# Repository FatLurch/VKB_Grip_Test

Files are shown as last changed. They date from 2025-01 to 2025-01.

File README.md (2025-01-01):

# VKB_Grip_Test

Basic Arduino Joystick interface to VKB MCG Pro grip

## Disclaimer

This information is provided without warranty - USE AT YOUR OWN RISK. 
Also, if you're looking for elegant design or code, you are in the wrong place.

## Overview

This project is intended to wire an Arduino Pro Micro directly to a VKB MCG Pro grip so that the Arduino can output the status of the grip as a Joystick using standard Windows joystick drivers.

## Circuit

The VKB grip uses a weird half-duplex UART line to transmit and recieve. In layman's terms, The TX and RX are tied together.

For my specific build I had a few Arduino Pro Micros laying around. This complicated things a bit since it uses 5V UART (The VKB grip is using 3.3V). There's a chance the UART pin on the STM32 microcontroller in the grip is 5V tolerant, but I wasn't feeling gutsy enough to try it, even if I were to dig in and verify the pin per the spec sheet. Ref: [https://community.st.com/t5/stm32-mcus-products/stm-uart-communication-voltage/td-p/288531](https://community.st.com/t5/stm32-mcus-products/stm-uart-communication-voltage/td-p/288531) 

The Micro also differentiates Serial (the USB com port) from Serial1 (Pins 0 & 1). If you're targeting this sketch for another type of board, you may need to go in and adjust these references.

My specific Arduino appeared to be outputting closer to 4V than 5V on the TX pin when measured with an oscillioscope. The two resistors act as a voltage divider to bring the TX voltage from the Arduino down to about 3.2V. The RX pin on my Arduino accepted the 3.3V signal from the VKB grip directly. 

To get the grip to "talk", an interrogation packet (a few hex characters) are required to be sent to the grip. In my code I'm simply ignoring this message when it's recieved by the Arduino (because the TX and RX UART pins are tied together).

Starting with a 3.3V Arduino should eliminate the need for the voltage divider and the voltage regulator.
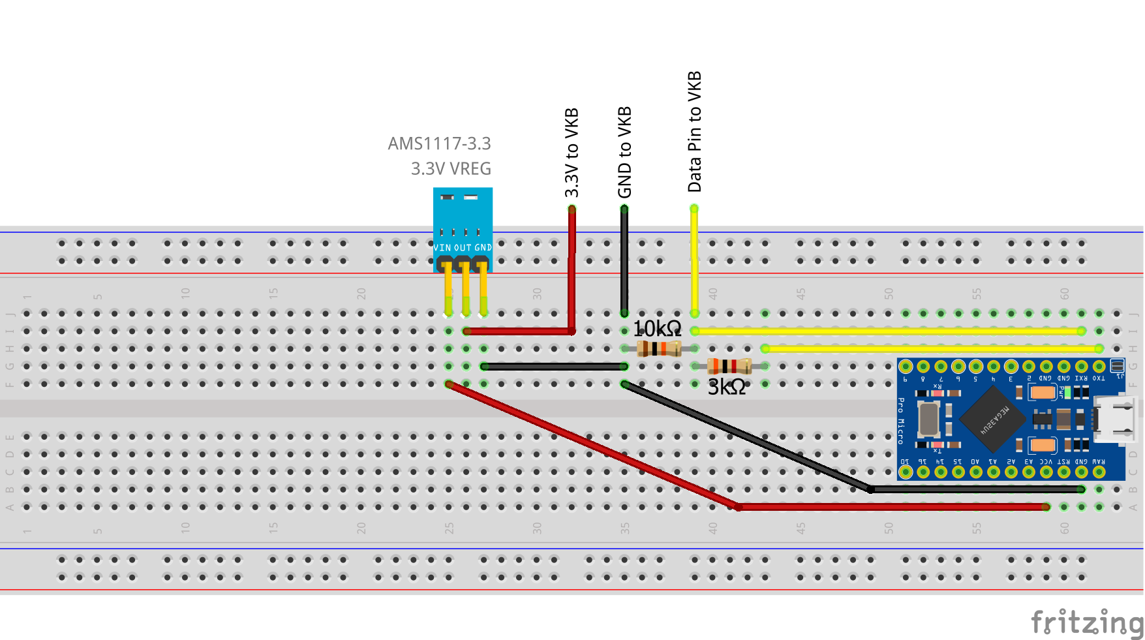
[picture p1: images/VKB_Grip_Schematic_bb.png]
Circuit Layout


All 32 possible buttons are mapped. You can view their status using "Set up USB game controllers" in Windows
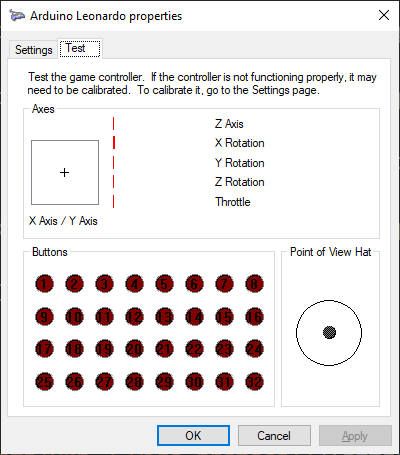
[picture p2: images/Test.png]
Testing


To wire to the grip itself, I used a 3 pin JST Molex PicoBlade 1.25mm style connector from this kit on Amazon: https://www.amazon.com/gp/product/B08RMQP6YP/ref=ppx_yo_dt_b_search_asin_title?ie=UTF8&psc=1

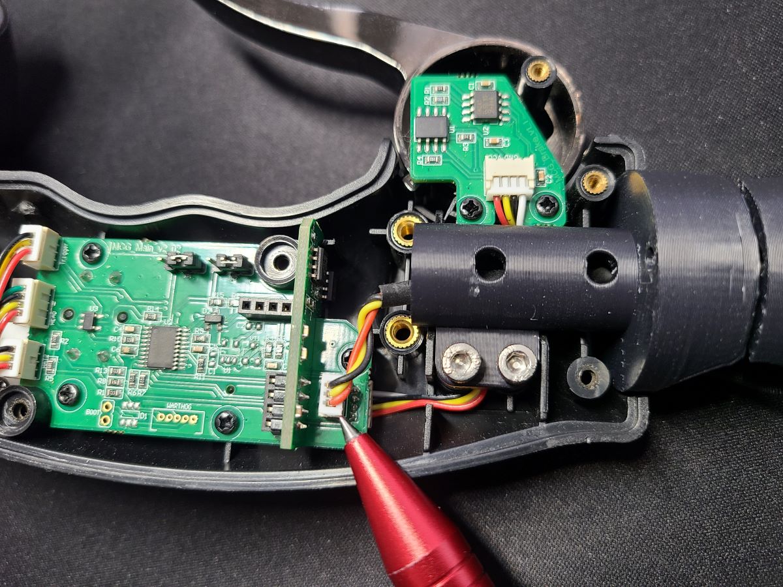
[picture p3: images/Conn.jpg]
Connector


## Sketch

** WHEN COMPILING THIS CODE ON ARDUINO MICRO CLONES BOARDS, YOU'LL LIKELY NEED TO SET THE BOARD TYPE TO ARDUINO LEONARDO **

The two analog hats are mapped both as analog outputs, and as digital "buttons" for up, down, left and right. The flip up analog trigger is mapped as a button when fully clicked and as an analog axis.

The math for calculating the analog positions is pretty rough and could use some work.

Currently, grip Z twist isn't incorperated because I'm not using it in my application and I don't want to build a custom PCB and mount to interface to the pogo pins in the twist adapter.

Previous breadcrumbs on decoding the grip protocol: [https://www.reddit.com/r/HotasDIY/comments/lckamn/vkb_3_wire_protocol/](https://www.reddit.com/r/HotasDIY/comments/lckamn/vkb_3_wire_protocol/)

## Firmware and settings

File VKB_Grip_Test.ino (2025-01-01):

/*
 * Created 12/31/2024 by Fat_Lurch, built upon the SerialPassthrough sketch by Erik Nyquist
 * 
 * This sketch sets up the Arduino to communicate with a VKB MCG Pro grip and act as a Joystick in Windows
 * 
 * A 3k and a 10k resistor are used in a voltage divider to lower the output voltage of the TX pin (measured as ~4V before voltage divider)
 * 
 * ### WHEN COMPILING THIS CODE ON ARDUINO MICRO CLONES BOARDS, YOU'LL LIKELY NEED TO SET THE BOARD TYPE TO ARDUINO LEONARDO ###
 */

#include "Joystick.h"

Joystick_ Joystick;

unsigned long previousMillis = 0;

const long interval = 10; //The loop will fire after this many milliseconds
   
char hexOut[8]; 

uint8_t buffer[100] = {};

uint8_t byteIndex = 0;

//static uint8_t interrogation[] = {0xA5, 0x09, 0x11, 0x98, 0x00, 0x00, 0x00, 0xA5, 0xAB};

void setup() {
  Serial.begin(500000);
  Serial1.begin(500000);
  Joystick.begin();
  Joystick.setThrottleRange(105, 830);
  Joystick.setXAxisRange(-329, 280);
  Joystick.setYAxisRange(-130, 145);
  Joystick.setRzAxisRange(350, 1800);
  Joystick.setRyAxisRange(-2900, 2900);   //Master Mode hat y-axis
  Joystick.setRxAxisRange(-2800, 2800);   //Master Mode hat x-axis
}

void loop() {

  unsigned long currentMillis = millis();

  //This is necessary because of the way the Micro handles serial. Reference the SerialPassthrough sketch in examples > communication
  if (Serial1.available()) {     // If anything comes in Serial1 (pins 0 & 1) (Vs Serial which is the USB interface)
    buffer[byteIndex] = Serial1.read();
    byteIndex++;
  }

  if (currentMillis - previousMillis >= interval) {
    
    previousMillis = currentMillis;

    //This is the "interrogation packet" for the VKB MCG Pro - 0xA5 0x09 0x11 0x98 0x00 0x00 0x00 0xA5 0xAB
    Serial1.write(0xA5);
    Serial1.write(0x09);
    Serial1.write(0x11);
    Serial1.write(0x98);
    Serial1.write(0x00);
    Serial1.write(0x00);
    Serial1.write(0x00);
    Serial1.write(0xA5);
    Serial1.write(0xAB);

    if(byteIndex == 43) //i.e. if it's a good packet
    {
      for(uint8_t i = 0; i < byteIndex; i++)
      {
        //Display of the raw hex coming from the grip. I'd manipulate one control at a time to see which bytes were reacting, then I'd focus on those bytes and try to decode them

        //sprintf(hexOut, "%02X", buffer[i]);
        //Serial.print(hexOut);
        //Serial.print(" ");
        
      }
      //Serial.print(" - ");

      int byteToTest = 22;

      /*
      //Display the individual bits in the byte of interest to see which bit starts reacting first
      Serial.print(bitRead(buffer[byteToTest], 7), BIN);
      Serial.print(bitRead(buffer[byteToTest], 6), BIN);
      Serial.print(bitRead(buffer[byteToTest], 5), BIN);
      Serial.print(bitRead(buffer[byteToTest], 4), BIN);
      Serial.print(bitRead(buffer[byteToTest], 3), BIN);
      Serial.print(bitRead(buffer[byteToTest], 2), BIN);
      Serial.print(bitRead(buffer[byteToTest], 1), BIN);
      Serial.print(bitRead(buffer[byteToTest], 0), BIN);
      Serial.print(" - ");
      */

      //Tests for each byte. 
      //I was starting with a bitmask of B00000000 and then "turning on" the most significant bit. I'd then sweep the range to see if the result was incrementing/decrementing correctly and smoothly
      //If turning on a bit caused non-linear behavior, I'd set an inversion mask bit to correct
      //At the end I'd try using an offset bit mask to get the swept range (e.g. from x to - x)
      //The bitshifts (<< and >>) were to rearrange bits to the correct spot. e.g. the first bit on a signed value needs to be the left most bit, even though that makes for a silly large number

      //                          Bit Mask    Inv Mask     offset Mask
      //int test = ((buffer[24] & B00011111 ^ B00001001) + B00000001 << 11);
      //int test2 = ((buffer[23] & B11111111 ^ B11011000) + B01100000 << 3);  //
      //int test3 = (test + test2) >> 3;// 
      
      
      //Serial.print(test);
      //Serial.print(" - ");
      //Serial.print(test2);
      //Serial.print(" - ");
      Serial.print(test3);
      
      Serial.println("");

      // Digital outputs
      Joystick.setButton(0, bitRead(buffer[40], 7));    //Forward Trigger
      Joystick.setButton(1, bitRead(buffer[38], 5));    //1st stage of two stage trigger
      Joystick.setButton(2, !bitRead(buffer[38], 6));   //2nd stage of two stage trigger
      Joystick.setButton(3, bitRead(buffer[39], 7));    //Grey round button to the right of PC hat
      Joystick.setButton(4, !bitRead(buffer[39], 5));   //Grey round button to the right of MANVR hat
      Joystick.setButton(5, bitRead(buffer[39], 6));    //Red round button to the left of MANVR hat
      Joystick.setButton(6, bitRead(buffer[38], 7));    //Black ring finger button below reset hat
      Joystick.setButton(7, bitRead(buffer[40], 4));    //Reset hat center click
      Joystick.setButton(8, !bitRead(buffer[40], 2));   //Reset hat left click
      Joystick.setButton(9, !bitRead(buffer[40], 0));   //Reset hat back click
      Joystick.setButton(10, bitRead(buffer[40], 3));   //Reset hat right click
      Joystick.setButton(11, !bitRead(buffer[40], 1));  //Reset hat forward click
      Joystick.setButton(12, bitRead(buffer[38], 4));   //PC hat center click
      Joystick.setButton(13, bitRead(buffer[38], 3));   //PC hat left click
      Joystick.setButton(14, !bitRead(buffer[38], 1));  //PC hat down click
      Joystick.setButton(15, bitRead(buffer[38], 2));   //PC hat right click
      Joystick.setButton(16, bitRead(buffer[38], 0));   //PC hat up click
      Joystick.setButton(17, bitRead(buffer[40], 5));   //Gate Cont hat click
      Joystick.setButton(18, bitRead(buffer[41], 7));   //Gate Cont hat left
      Joystick.setButton(19, bitRead(buffer[41], 4));   //Gate Cont hat down
      Joystick.setButton(20, !bitRead(buffer[41], 5));  //Gate Cont hat right
      Joystick.setButton(21, !bitRead(buffer[41], 6));  //Gate Cont hat right
      Joystick.setButton(22, !bitRead(buffer[40], 6));  //Master mode hat click
      Joystick.setButton(23, bitRead(buffer[41], 3));   //Master mode hat left
      Joystick.setButton(24, bitRead(buffer[41], 0));   //Master mode hat down
      Joystick.setButton(25, !bitRead(buffer[41], 1));  //Master mode hat right
      Joystick.setButton(26, bitRead(buffer[41], 2));   //Master mode hat right
      Joystick.setButton(27, !bitRead(buffer[39], 4));  //DC hat click
      Joystick.setButton(28, !bitRead(buffer[39], 0));  //DC hat back
      Joystick.setButton(29, !bitRead(buffer[39], 3));  //DC hat down
      Joystick.setButton(30, bitRead(buffer[39], 1));   //DC hat down
      Joystick.setButton(31, !bitRead(buffer[39], 2));  //DC hat up

      // Analog outputs
      Joystick.setThrottle(((buffer[30] & B00000011) << 8) + buffer[29] ^ B10011111);       //Brake Lever
      Joystick.setRzAxis(((buffer[32] & B00111111 ^ B00101011) << 5) + ((buffer[31] & B11111000 ^ B01011000) >> 3));    //Analog trigger
      Joystick.setXAxis((((buffer[28] & B00111111 ^ B00000111) << 10) + ((buffer[27] & B11110000 ^ B01100000) << 2)) * -0.015625);    //Gate Cont Hat X axis
      Joystick.setYAxis((((buffer[26] & B00111111 ^ B00110001) << 10) + ((buffer[25] & B11100000 ^ B11100000) << 2)) * -0.0078125);   //Gate Cont Hat Y Axis
      Joystick.setRyAxis((((buffer[22] & B00011111 ^ B00001110) + B00000010 << 11) + ((buffer[21] & B11111111 ^ B11001000) + B00001000 << 3)) >> 3);  //Master Mode Hat Y Axis
      Joystick.setRxAxis((((buffer[24] & B00011111 ^ B00001001) + B00000001 << 11) + ((buffer[23] & B11111111 ^ B11011000) + B01100000 << 3)) >> 3);  //Master Mode Hat X Axis

    }

    byteIndex = 0;

  }

}

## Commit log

2025-01-01 Added basic Fritzing documentation
    [VKB_Grip_Schematic.fzz]
2025-01-01 Correctly formatted raw hex stream to make reverse-engineering easier
    [VKB_Grip_Test.ino]
2025-01-01 Added basic filtering for good packets
2025-01-01 Correctly displaying the status of the trigger switch in the serial stream output
    [VKB_Grip_Test.ino]
2025-01-01 Got the trigger working as button 0 on an emulated joystick
2025-01-01 Have both triggers mapped to joystick buttons
2025-01-01 All 32 buttons mapped and working
2025-01-01 Captured the two most significant bits for the brake function. The rest is in byte offset 29
2025-01-01 Analog brake axis working
2025-01-01 GAte Cont Y-axis analog working. Removed map calls and used Joystick.setXXXaxis commands instead
2025-01-01 Working X Axis for Gate Cont hat
2025-01-01 Updated fritzing figure to show resistor values
    [VKB_Grip_Schematic.fzz]
